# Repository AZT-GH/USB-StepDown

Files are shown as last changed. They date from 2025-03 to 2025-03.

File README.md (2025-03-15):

# USB-StepDown
A buck converter + ldo that converts non power delivery USB (C to C compatible) to 3V3 and 1V8. 
Particularily useful for embedded development.

## Design Goals
I created this design so that I could test another board that required 3V3 and 1V8 inputs. (For use with PixArt PMW3360) Some of the key goals were for the pcb to be as compact as possible as I wanted to reuse portions of the schematic on other boards. I added schottky diodes at the expense of efficiency so that the board was not reliant on usb availability. This board can regulate up to 6v (~7v possible but not reccomended due to the LDO) to 3V3 and 1V8. The efficiency is not great due to the voltage drop of the diodes however this was not a priority for me as this board will only be used in a testing environment.

## Version History

V1 - Initial design ( not on repository :0 )

V1.1 - Fixed missing trace from feedback resistor to ground= and tidied up some trace paths.

## License

This project is licensed under the **CERN Open Hardware Licence – Strongly Reciprocal (CERN OHL-S)**.

By using, modifying, or distributing this hardware, you agree to comply with the terms of the CERN OHL-S v2.0.  
See the full license text in the [LICENSE](LICENSE.txt) file.

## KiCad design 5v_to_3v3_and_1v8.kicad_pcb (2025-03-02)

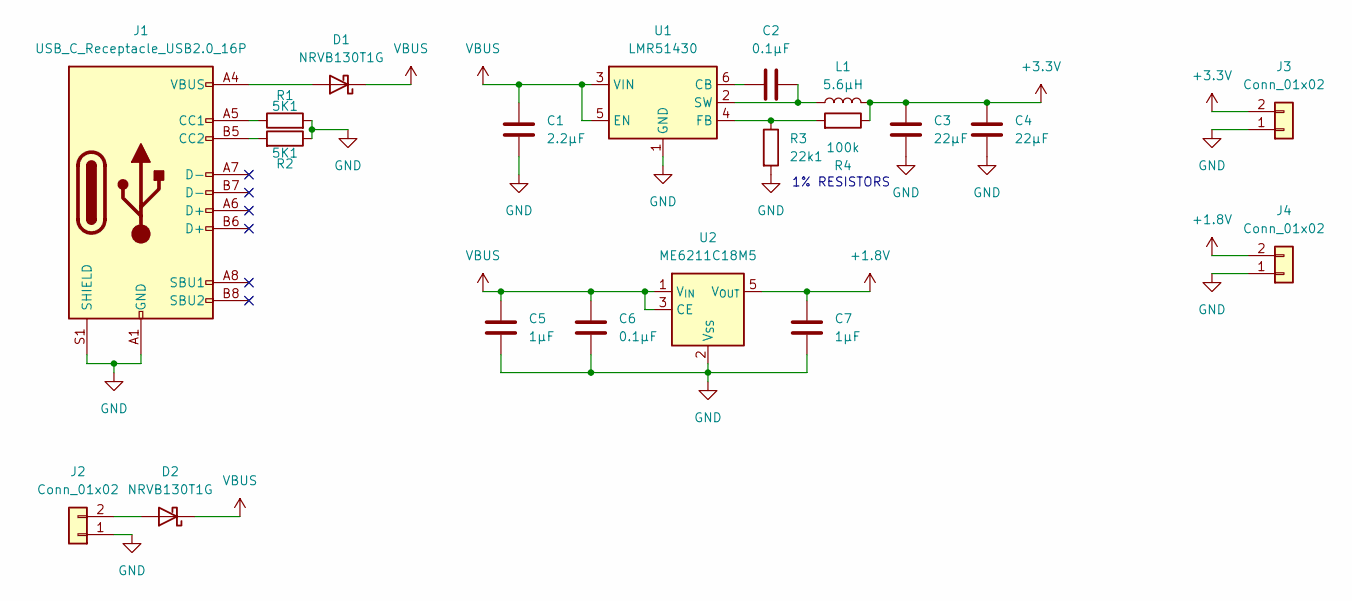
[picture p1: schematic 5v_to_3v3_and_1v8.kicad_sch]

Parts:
C1: 2.2µF; C_0805_2012Metric
C2, C6: 0.1µF; C_0805_2012Metric
C3, C4: 22µF; C_0805_2012Metric
C5, C7: 1µF; C_0805_2012Metric
D1, D2: NRVB130T1G; D_SOD-123
J1: USB_C_Receptacle_USB2.0_16P; USB_C_Receptacle_G-Switch_GT-USB-7010ASV
J2, J3, J4: Conn_01x02; PinHeader_1x02_P2.54mm_Vertical; Part Number 1-0201FBV0T
L1: 5.6µH; L_Cenker_CKCS3015
R1, R2: 5K1; R_0805_2012Metric
R3: 22k1; R_1206_3216Metric
R4: 100k; R_1206_3216Metric
U1: LMR51430; SOT-23-6
U2: ME6211C18M5; SOT-23-5

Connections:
+1.8V: C7.1, J4.2, U2.5 (V_{OUT})
+3.3V: C3.1, C4.1, J3.2, L1.2, R4.1
GND: C1.2, C3.2, C4.2, C5.2, C6.2, C7.2, J1.A1 (GND), J1.A12 (GND), J1.B1 (GND), J1.B12 (GND), J1.S1 (SHIELD), J2.1, J3.1, J4.1, R1.2, R2.1, R3.2, U1.1 (GND), U2.2 (V_{SS})
unnamed: D1.2 (A), J1.A4 (VBUS), J1.A9 (VBUS), J1.B4 (VBUS), J1.B9 (VBUS)
unnamed: D2.2 (A), J2.2
unnamed: J1.A5 (CC1), R1.1
unnamed: J1.B5 (CC2), R2.2
unnamed: C2.2, U1.6 (CB)
unnamed: R3.1, R4.2, U1.4 (FB)
unnamed: C2.1, L1.1, U1.2 (SW)
VBUS: C1.1, C5.1, C6.1, D1.1 (K), D2.1 (K), U1.3 (VIN), U1.5 (EN), U2.1 (V_{IN}), U2.3 (CE)

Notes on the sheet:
1% RESISTORS

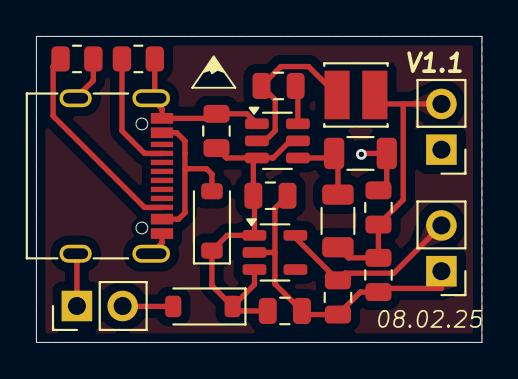
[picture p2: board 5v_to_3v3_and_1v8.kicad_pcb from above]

Board: 2 copper layers, 24.8 x 17.0 mm, 20 parts (0 on the bottom side), 11 nets.
